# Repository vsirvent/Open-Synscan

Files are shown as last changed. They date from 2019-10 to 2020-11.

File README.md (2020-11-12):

# OPEN-SYNSCAN

## Intro

Open-Synscan is a free open source project to create your own GOTO motorization system for your equatorial telescope mount (like eq-3, eq-5, exos-2, etc...). It implements skywatcher synscan protocol and you can use any application compliant with Synscan protocol to manage the telescope mount over WIFI network connection.

Open-Synscan runs on a ESP8266 to control 2 step motors and works with Skywatcher SynScan protocol using WIFI connection.

Tested with EQMOD and Android Synscan PRO.

EQMOD only works with serial comm port, so SerialCom2Wifi app must be used (https://github.com/vsirvent/SynscanCom2Wifi).

## Getting the code

Open-Synscan runs with Sming Framework (https://github.com/SmingHub/Sming/), so first step is to clone and setup sming enviroment:

```
git clone https://github.com/SmingHub/Sming.git
```

Then clone Open-Synscan:

```
git clone https://github.com/vsirvent/Open-Synscan.git
```

## Compilation

Now we need to edit file "Makefile-user.mk" located at "Synscan" folder and set SMING_HOME folder. 
Edit line:

```
SMING_HOME=#Write Sming folder here. Ex: /home/vicen/src/Sming/Sming/
```

```
make
```

## Flash to ESP8266

Make sure ESP8266 boots in flash mode (plug FLASH jumper in control PCB and reboot).

Then type:

```
make flash
```

## Configure motor values

Each mount can have a different number of gear teeth on DEC and RA axis. You can check your mount values at <http://eq-mod.sourceforge.net/prerequisites.html>. You must set the correct values of the gear teeth number and the GT2 wheel teeth numbers at Motor.h constant members:

```
  Motor.h
  ...
	static const u32 MOUNT_RATIO = 144; //The mount gear teeth number
	static const u32 GEAR_RATIO_NUM = 60; //Big GT2 wheel teeth number
	static const u32 GEAR_RATIO_DEN = 16; //Small GT2 wheel teeth number
	const float STEP_DEGREE = 0.9f; //Here the step degree of the motors
  ...
```

## Debug

You can debug using serial port at 115200bps 8n1 or by ethernet network receiving UDP packets with netcat. To get traces with netcat type the following commands:

```
nc -u [open-synscan-ip] 6667
log on #To start receiving traces
log off #To stop receiving traces
```
## Usage

After boot, open-synscan will create a WIFI network "Synscan" with password "12345678". You can then connect PC computer/tablet or phone, start the control application (EQMOD, SynScan PRO), connect the application to the mount and control it using Synscan protocol.

## Making the ESP8266 control board and setting up step motors

The PCB control board schematics based on ESP8266 chip is available here:

https://circuitmaker.com/Projects/Details/Vicente-Sirvent/SynscanMotor

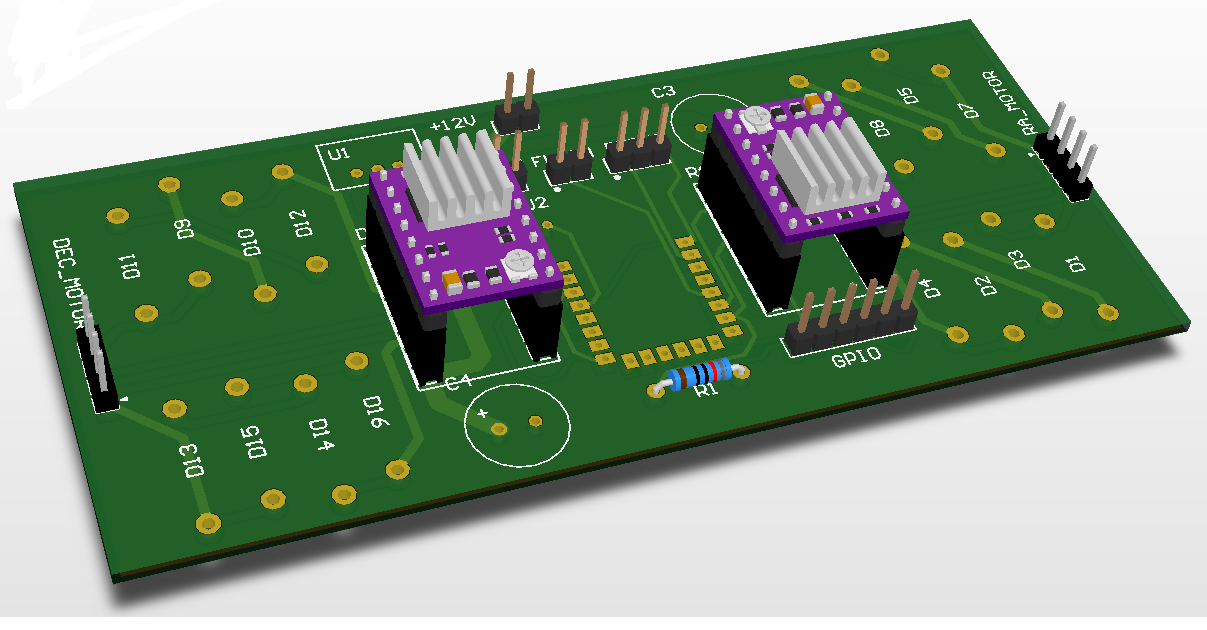
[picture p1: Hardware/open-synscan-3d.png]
screeshot


Motors are mounted in the telescope mount with 3d print models available in "3dFiles" folder. Step motors use gt2 6mm with wheels (60 and 16 teeth) + 158mm gt2 6mm closed belts to move the gears of the mount.

## Demo

This demo video shows Open-Synscan working with Cartes du Ciel + EQMOD + SynscanCom2Wifi (https://github.com/vsirvent/SynscanCom2Wifi) to control a Meade LXD75 mount using WIFI connection:

IMAGE ALT TEXT HERE (https://www.youtube.com/watch?v=-moP3M088pw)

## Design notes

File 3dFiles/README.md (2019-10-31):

This folder contains 3d files for printing motor supports. 

Same design used for both RA and DEC axiS.

STL files can be used for direct 3d print.

FCStd files are original designs and can be edited with Freecad.

Tested on EXOS-2 mount.

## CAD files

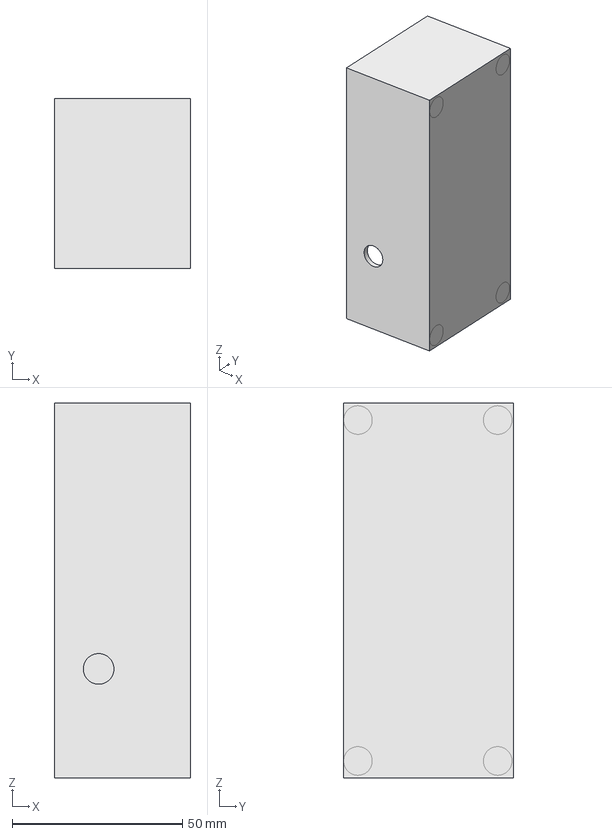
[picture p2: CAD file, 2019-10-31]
3dFiles/PCB_BOX.FCStd
40.0 x 50.0 x 110.0 mm

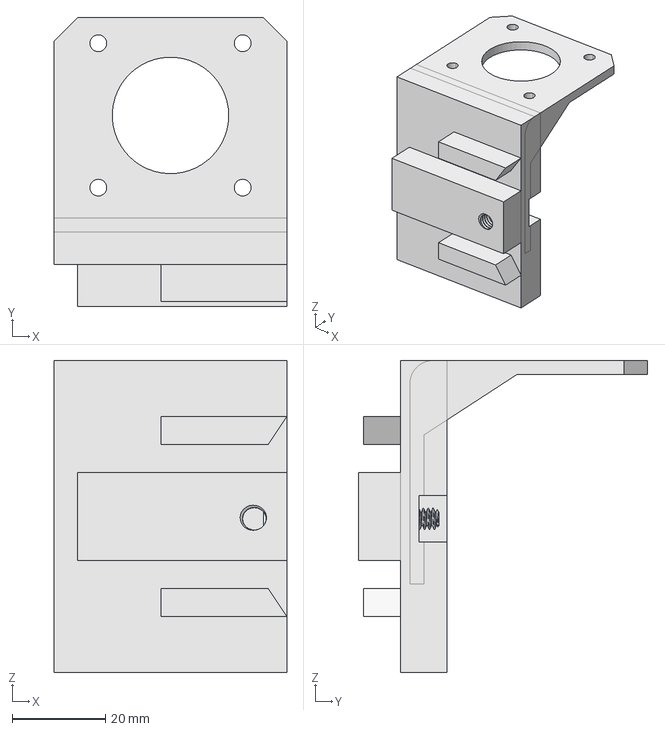
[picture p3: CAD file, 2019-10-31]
3dFiles/SUPPORT.FCStd
50.0 x 62.0 x 67.0 mm

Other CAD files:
3dFiles/SUPPORT.stl

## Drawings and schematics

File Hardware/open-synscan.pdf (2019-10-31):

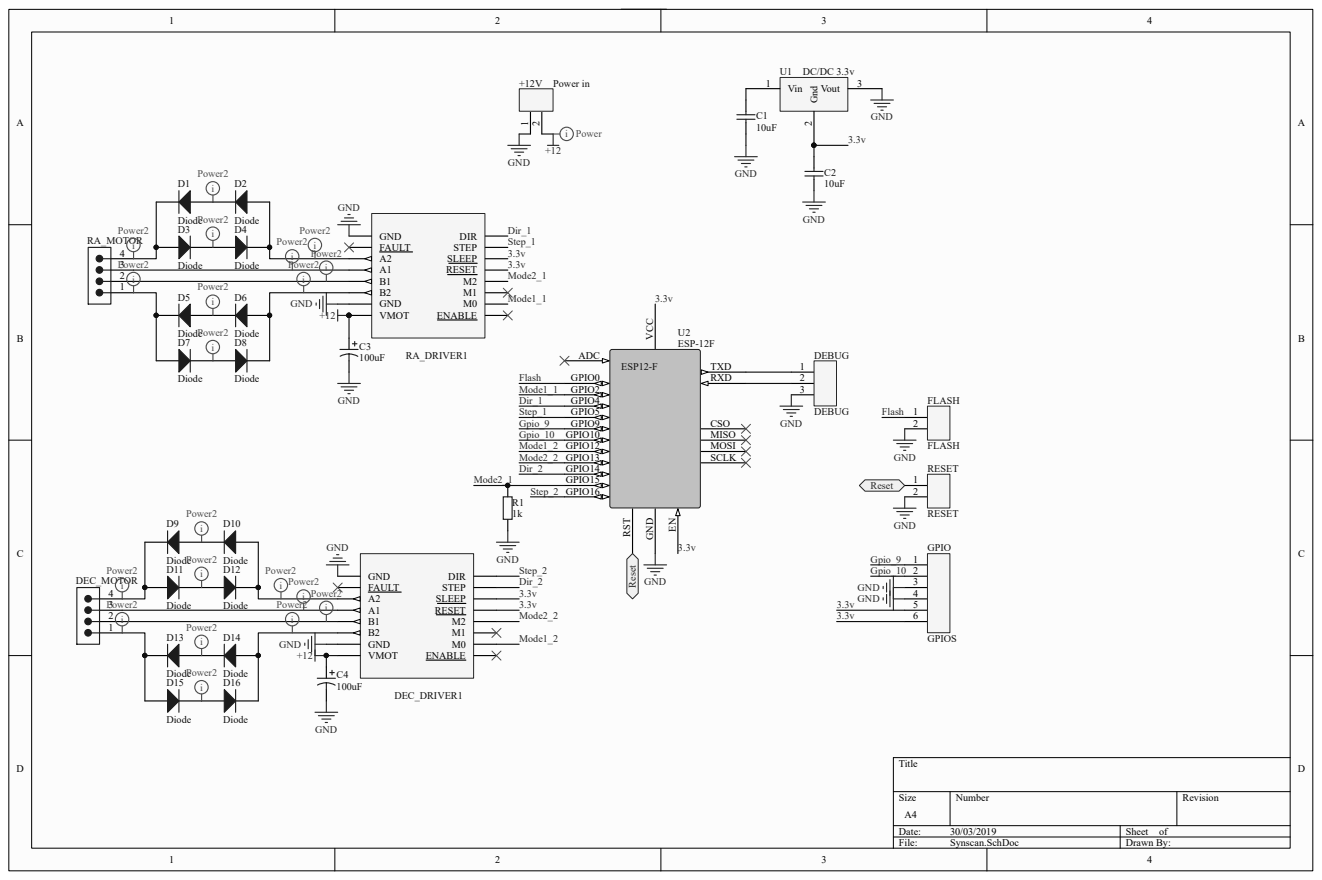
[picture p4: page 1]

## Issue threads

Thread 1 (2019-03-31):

Calculate correct mount limits

vsirvent, 2019-03-31:
Recheck algorithm for calculate mount limits as current one is too severe.

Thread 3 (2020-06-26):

Supporting ESP32 arch. Porting to Sming V4.1

nachoplus, 2020-06-26:
Hi,

Great job!

As far as I understand this software/hardware behave as synscan replacement. I would like to ask you if can be used also with synscan android app.

Thanks!

nachoplus, 2020-07-09:
Sorry  for this stupid question. It is clearly state in the docs.
I answer myself. Yes! Its compatible with android app.
BTW: I compile and flash using Sming v4.1 framework. I made some minor adaptations. You can check on my fork: https://github.com/nachoplus/Open-Synscan

vsirvent, 2020-07-09:
Hi!

Good job with the adaptation, I see you also found a bug in an array declaration size.

Did you run the code on the board? Is it running correctly on your mount?

Do not hesitate to ask any question to make it work.

I'll merge your code asap.

Regards!

nachoplus, 2020-07-10:
Thanks!

I think it is too soon to merge. I would like to do some more testing but if you want I will send you a pull request.

The code compiles seamlessly for the ESP8266 and ESP32 architectures thanks to the work of the people at Sming.
At the moment I have only loaded it into several ESP8266MOD (standalone and nodemcu). I will test it soon on an ESP32-CAM board.

I have not yet tested it with motors, only with the oscilloscope. I also be able to connect and command with synscan pro Android app.

BTW: While implementing different pinouts  for my boards I have found a discrepancy in the DEC AXIS pinout between the code and the schema. The code says:
```
mDirPin = 13;
mStepPin = 12;
mMode[0] = 14;
mMode[1] = 16;
```
but the schematic show DirPin=14, StepPin=16, Mode[0]=12,Mode[1]=13. I guest that is a typo in the schematic and I kept the code pinout.

Regards!

nachoplus, 2020-08-05:
I am having problems with ESP32 port. Every looks OK at when compiling but not at running time. It looks a failure from the outgoing Sming ESP32 port. I wait until they(or me) will fix.

I'll inform you.

Closed 2020-12-28.

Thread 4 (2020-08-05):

Help to support Open-synscan with pysynscan python package

nachoplus, 2020-08-05:
Hi Vicente,

Recently I developed a native python3 package to support  SkyWatcher synscan motor protocol. All my research was with Skywatcher AZ-GTI. Up today it is feature limited but I want to improve further to support more hardware (mainly yours hardware) and additional features (align routines, RA/DEC mount, sky model...). The final aim is to manage mounts programmatically for several proposes (satellite tracking, sky panorama, surveys...). Been a pure python package it is easy to integrate with others libraries (pyephem, skyfield, astropy...)

You can check my work on  https://nachoplus.github.io/pysynscan/  or the code itself on https://github.com/nachoplus/pysynscan

Also you can try by yourself installing it from pip "pip install synscan"

In this context I want to support Open-synscan hardware but I found several issues so could be great if you help me. I am sure that most of them come from different protocol interpretation, Open-synscan works flawless with synscan pro app but pysynscan do well with AZ-GTI hardware also...

I list some of them here:

* Only does goto in CW direction. It looks that it necessary to change motor direction but AZ-GTI manage by itself
* Not Alt/Az mode.
* No tracking at arbitrary speed

I am going to leave the development until September, you now, vacation time. Would be great if we can help each other to improve our respective projects!

Regards

vsirvent, 2020-08-07:
Hi!

Sure we can check the issues after holidays. Just let me know when you are available again and we can have a quick  conference so you can give me more details.

Regards,

Vicente

nachoplus, 2020-09-02:
Hi Vicente!

Finally I managed the issues by myself. I did a little reverse engineering of synscan pro app and I modified pysynscan to behave similar from the point of view of motor protocol.

Main issue was that Skywatcher AZ-GTI manage by itself motor direction when slewing but open-synscan not.

Now I can say pysynscan suport open-synscan!

I have published the new version 0.1.2 in https://pypi.org/project/synscan/ so anyone can install it easily with 'pip install synscan'

Sure I will need your help in the near future for further improvements.
We will keep in contact!
Nacho

Closed 2020-10-12.

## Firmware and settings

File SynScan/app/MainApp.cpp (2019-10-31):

/*
 * This file is part of the Open Synscan Project distribution (https://github.com/vsirvent/Synscan).
 * Copyright (c) 2019 Vicente Sirvent Orts.
 *
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
 * You should have received a copy of the GNU General Public License
 * along with this program. If not, see <http://www.gnu.org/licenses/>.
 */

#include "MainApp.h"
#include "TickTimer.h"

MainApp::MainApp() {
	Logger::notice("MainApp: Initializing objects...");
	mRaMotor = new Motor(EAxis::AXIS_RA);
	mDecMotor = new Motor(EAxis::AXIS_DEC);
	mUdpComm = new UdpComm();
	//mSerialComm = new SerialComm();
	mOneSecTimer = new Timer();

	Logger::notice("MainApp: Setting callbacks...");
	AppTimer.addListener(mRaMotor);
	AppTimer.addListener(mDecMotor);

	mUdpComm->setListener(this);
	//mSerialComm->setListener(this);

	AppTimer.setIntervalTicks((float)TickTimer::TICK_FREQ/(float)Defines::TIMER_FREQ);

	Logger::notice("MainApp: Start timers...");
	AppTimer.start(true);
//	mOneSecTimer->initializeMs(1000, std::bind(&MainApp::oneSecTick, this)).start();
	mOneSecTimer->initializeMs(1000, TimerDelegate(&MainApp::oneSecTick, this)).start();

	Logger::notice("MainApp: Init done");
}

MainApp::~MainApp() {
	AppTimer.stop();
	mOneSecTimer->stop();
	delete mOneSecTimer;
	delete mRaMotor;
	delete mDecMotor;
	delete mUdpComm;
	//delete mSerialComm;
}

void
MainApp::oneSecTick() {
	mRaMotor->printInfo();
	mDecMotor->printInfo();
	mUdpComm->sendDiscovery();
}

void
MainApp::onCommandReceived(Comm* comm, Command* cmd) {
	if (cmd != NULL) {
		Reply* reply = NULL;
		if (cmd->getAxis() == EAxis::AXIS_RA) {
			reply = mRaMotor->processCommand(cmd);
		} else if (cmd->getAxis() == EAxis::AXIS_DEC) {
			reply = mDecMotor->processCommand(cmd);
		} else if (cmd->getAxis() == EAxis::AXIS_BOTH) {
			Logger::notice("onCommandReceived: Command %d for both axis", cmd->getCmd());
			reply = mRaMotor->processCommand(cmd);
			Reply* reply2 = mDecMotor->processCommand(cmd);
			delete reply2;
		}
		if (reply != NULL) {
			comm->sendReply(reply);
			delete reply;
		}
	}
}

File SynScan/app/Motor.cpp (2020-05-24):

/*
 * This file is part of the Open Synscan Project distribution (https://github.com/vsirvent/Synscan).
 * Copyright (c) 2019 Vicente Sirvent Orts.
 *
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
 * You should have received a copy of the GNU General Public License
 * along with this program. If not, see <http://www.gnu.org/licenses/>.
 */

#include "Motor.h"
#include "MainApp.h"

#define STEP_TO_FREQ(x) (x!=0)?(Defines::TIMER_FREQ / x):INFINITE;
#define FREQ_TO_STEP(x) (x!=0)?(Defines::TIMER_FREQ / x):INFINITE;

Motor::Motor(EAxis axis) {

	Logger::notice("Motor[%d]: Initializing %s motor...", axis,
			axis == EAxis::AXIS_RA ? "RA" : "DEC");
	mAxis = axis;
	if (mAxis == EAxis::AXIS_RA) {
		mDirPin = 4;
		mStepPin = 5;
		mMode[0] = 2;
		mMode[1] = 15;
		mMaxCount = 9484409;
		mMinCount = 4288680;
		mPosition = degreeToPosition(0.0f);
	} else if (mAxis == EAxis::AXIS_DEC) {
		mDirPin = 13;
		mStepPin = 12;
		mMode[0] = 14;
		mMode[1] = 16;
		mMaxCount = degreeToPosition(165.0f);
		mMinCount = degreeToPosition(15.0f);
		mPosition = degreeToPosition(90.0f);
	}

	pinMode(mDirPin, OUTPUT);
	pinMode(mStepPin, OUTPUT);
	pinMode(mMode[0], OUTPUT);
	pinMode(mMode[1], OUTPUT);

	//init pins
	setDir(EDirection::CW);
	digitalWrite(mStepPin, 0);

	//microstep active
	digitalWrite(mMode[0], 1);
	digitalWrite(mMode[1], 1);
	mMicroStep = true;

	Serial.printf("MOUNT_RATIO = %d\n", MOUNT_RATIO);
	Serial.printf("GEAR_RATIO_NUM = %d\n", GEAR_RATIO_NUM);
	Serial.printf("GEAR_RATIO_DEN = %d\n", GEAR_RATIO_DEN);
	Serial.printf("GEAR_RATIO = %f\n", GEAR_RATIO);
	Serial.printf("HIGH_SPEED_RATIO = %d\n", HIGH_SPEED_RATIO);
	Serial.printf("STEP_DEGREE = %f\n", STEP_DEGREE);
	Serial.printf("STEPS_PER_WORM_REV = %d\n", STEPS_PER_WORM_REV);
	Serial.printf("STEPS_PER_RA_REV = %d\n", STEPS_PER_RA_REV);
	Serial.printf("SIDERAL_STEP_COUNT = %f\n", SIDERAL_STEP_COUNT);
	Serial.printf("SIDERAL_PERIOD_FREQ = %d\n", SIDERAL_PERIOD_FREQ);
	Serial.printf("TIMER_FREQ = %d\n", Defines::TIMER_FREQ);

	m100msecTimer = new Timer();
	m100msecTimer->initializeMs(100, TimerDelegate(&Motor::on100msecTick, this)).start();

	Logger::notice("Motor[%d]: Init done", mAxis);
}

Motor::~Motor() {
	m100msecTimer->stop();
	delete m100msecTimer;
}

void Motor::setMicroSteps(bool active) {
	//always active
	if (HIGH_SPEED_RATIO == 1) {
		active = true; //same high and low speed
	}
	if (mMicroStep != active) {
		if (active) {
			digitalWrite(mMode[0], 1);
			digitalWrite(mMode[1], 1);
		} else {
			digitalWrite(mMode[0], 1);
			digitalWrite(mMode[1], 0);
		}
		mMicroStep = active;
	}
}

int Motor::updateCurrentStepPeriod(u32 target_step) {
	int ret = target_step;
	mTargetStepPeriod = target_step;
	if (mCurrentStepPeriod != target_step) {
		int current_step_freq = mCurrentStepFreq;
		int target_step_freq = (target_step!=0)?(Defines::TIMER_FREQ / target_step):INFINITE;
		int diff_freq = abs(current_step_freq - target_step_freq);
		//Only apply acceleration if diff is greater than sideral freq.
		if (diff_freq > SIDERAL_PERIOD_FREQ) {
			int block_freq = diff_freq / 8;
			if (block_freq < SIDERAL_PERIOD_FREQ) {
				block_freq = SIDERAL_PERIOD_FREQ;
			}

			if (current_step_freq < target_step_freq) {
				current_step_freq += block_freq;
				if (current_step_freq > target_step_freq) {
					current_step_freq = target_step_freq;
				}
			} else if (current_step_freq > target_step_freq) {
				current_step_freq -= block_freq;
				if (current_step_freq < target_step_freq) {
					current_step_freq = target_step_freq;
				}
			}
			ret = (current_step_freq!=0)?(Defines::TIMER_FREQ / current_step_freq):INFINITE; //new step period
			//Due to int division freq operations can result to same period, so we force increase/decrease
			if (ret == mCurrentStepPeriod) {
				if (target_step < ret) {
					ret--;
				}else{
					ret++;
				}
			}
		}
	}
	if (ret < 4) {
		ret = 4; //minimum 4 periods per step
	}
	return ret;
}

void Motor::setStepPeriod(u32 period) {
	u32 speed = (period!=0)?(mSideralStepPeriod / period):INFINITE;
	if (!mMicroStep) {
		speed *= HIGH_SPEED_RATIO;
	}

	//Limit speed to mFastStepMult
	if (speed > mFastStepMult) {
		period = mSideralStepPeriod / mFastStepMult;
		if (!mMicroStep) {
			period *= HIGH_SPEED_RATIO;
		}
	}
	mStepPeriod = period;
}

void Motor::setDir(EDirection dir) {
	if (dir != mDir) {
		Logger::notice("Motor[%d]: Direction: %s", mAxis,
				dir == EDirection::CW ? "CW" : "CCW");
		mDir = dir;
		if (mDir == EDirection::CW) {
			digitalWrite(mDirPin, 1);
		} else {
			digitalWrite(mDirPin, 0);
		}
	}
}

int Motor::degreeToPosition(float degree) {
	return (int) ((0x800000 + (int) (degree / DEGREE_PER_STEP)));
}

void Motor::stop() {
	mMoving = false;
	digitalWrite(mStepPin, 0);
	mStepCount = 0;
}

void Motor::on100msecTick() {
	if (mType == ESlewType::GOTO) {
		//Stop if controller is not sending commands
		//(comm fail protection).
		if (mCommStatusWD++ >= mCommStatusTimeout) {
			mToStop = true;
		}

		if (mToStop) {
			//Decelerate to sideral speed and stop
			mCurrentStepPeriod = updateCurrentStepPeriod(mSideralStepPeriod);
			mCurrentStepFreq = (mCurrentStepPeriod!=0)?(Defines::TIMER_FREQ/mCurrentStepPeriod):INFINITE;
			if (mCurrentStepPeriod >= mSideralStepPeriod) {
				stop();
			}

		} else {
			if (mTargetPosition == INFINITE) {
				stop();
			}
			//Normal goto
			u32 remain = abs(mTargetPosition - mPosition) / 50;
			u32 elapsed = abs(mPosition - mOrigPosition) / 50;
			u32 mult = MIN(remain, elapsed);
			mult = MIN(mFastStepMult, mult);
			mult = MIN(mSideralStepPeriod, mult);

			if (!mMicroStep) {
				mult /= HIGH_SPEED_RATIO;
			}

			if (mult > 1) {
				mCurrentStepPeriod = (mSideralStepPeriod / mult);
			} else {
				mCurrentStepPeriod = ((int) (SIDERAL_STEP_COUNT / 2.0f));
			}
			mCurrentStepFreq = (mCurrentStepPeriod!=0)?(Defines::TIMER_FREQ/mCurrentStepPeriod):INFINITE;
		}
	} else {
		//Track
		int sideral = mSideralStepPeriod;
		//This code was not really used
		//if (mAutoGuideMode != 1000) {
		//	sideral = (sideral * 1000) / mAutoGuideMode;
		//}
		int target_period = mToStop ? sideral : mStepPeriod;
		mCurrentStepPeriod = updateCurrentStepPeriod(target_period);
		mCurrentStepFreq = (mCurrentStepPeriod!=0)?Defines::TIMER_FREQ/mCurrentStepPeriod:INFINITE;

		if (mCurrentStepPeriod >= mSideralStepPeriod && mToStop) {
			stop();
		}
	}
	if (mMoving) {
		//if ((mDir == EDirection::CW && mPosition > mMaxCount)
		//		|| (mDir == EDirection::CCW && mPosition < mMinCount)) {
			//Absolute position protection
			//TODO: Calculate correctly the limits, depending the RA position
			//DEC limit changed. The current limit algorithm is too hard.
		//	stop();
		//}
	}
	if (mIsPulseDone) {
		Logger::notice("Motor[%d]::on100msecTick: Pulse guide done", mAxis);
		mIsPulseDone = false;
	}
}
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

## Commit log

2019-03-02 Synscan Motor software to run on ESP8266.
2019-03-10 ADD: License header OPTIMIZATION: Removed low priority work from hw timer interrupt. ADD: Connection to wifi station.
2019-03-10 CHANGE: Motor version 2.0.5.0
2019-03-30 FIX: Project adapted to compile current Sming version at 30/3/2019 (commit #1653)
    [MainApp.cpp, Motor.cpp]
2019-03-30 CHANGE: Motor version 2.0.5.1. Compatible with last Sming version #1653.
2019-10-03 FIX: Traces and unused vars.
2019-10-31 ADD: Pulse guide message FIX: float division by 0
    [Commands.h, Logger.cpp, MainApp.cpp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]
2020-05-24 FIX: Freq to step period round error.
    [Motor.cpp, Motor.h]

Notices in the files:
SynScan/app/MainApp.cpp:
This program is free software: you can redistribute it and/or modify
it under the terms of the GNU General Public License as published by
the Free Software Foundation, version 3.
